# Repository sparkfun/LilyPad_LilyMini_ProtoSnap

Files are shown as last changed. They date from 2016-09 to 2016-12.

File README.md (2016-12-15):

LilyMini ProtoSnap
========================================

(https://cdn.sparkfun.com/assets/parts/1/1/9/0/5/14063-01.jpg)

[*LilyMini ProtoSnap (https://www.sparkfun.com/products/14063)*](https://www.sparkfun.com/products/14063)

The LilyMini ProtoSnap is a great way to create interactive e-textile circuits. At the center of the board is a pre-programmed LilyMini microcontroller connected to a LilyPad Light Sensor, LilyPad Button and two pairs of LilyPad LEDs.

Like other ProtoSnap boards, the LilyMini ProtoSnap has all of these parts connected together on the board, enabling you to play with the circuit before you sew. When you're ready to make your project, snap out the parts and sew them together!

The LilyMini ProtoSnap ships with pre-loaded code that exercises all the LilyPad pieces connected to it. The sample code has three modes, which can be selected by pressing the LilyPad Button on the bottom-left side of the ProtoSnap. The built-in RGB LED on the LilyMini will change color to indicate which mode has been selected:

* White: All LEDs on.
* Magenta: LEDs fade in and out in a breathing pattern. When the light sensor is covered, LEDs fade faster.
* Cyan/Blue: When the board is in darkness, the LEDs will twinkle (perfect for night-lights)

You can use the built-in code to make your own projects (see the hook-up guide below), or you can reprogram the LilyMini using the Arduino system . **Reprogramming instructions coming soon (1/1/17).** 

Repository Contents
-------------------

This repository includes the hardware design files and binaries for the release firmware. <br>
**Reprogramming information and source code are coming soon (1/1/17).** 

* **/Documentation** - Data sheets, additional product information
* **/Firmware** - Preinstalled code 
* **/Hardware** - Eagle design files (.brd, .sch)
* **/Production** - Production panel files (.brd)

Documentation
--------------
* **[Hookup Guide](https://learn.sparkfun.com/tutorials/lilymini-protosnap-hookup-guide)** - Basic hookup guide and example projects for the LilyMini ProtoSnap

License Information
-------------------

This product is _**open source**_! Please review the LICENSE.md file for license information. If you have any questions or concerns on licensing, please contact techsupport@sparkfun.com. This information is distributed as-is; no warranty is given.

Have fun! - Your friends at SparkFun.

Acknowledgement
---------------

We gratefully acknowledge the following people and groups for their open-source contributions:

* Arduino LLC and Atmel Corporation/Thibaut Viard for bringing Arduino support to the SAMD21.
* Justin Mattair of [Mattairtech, Inc.](https://www.mattairtech.com/) for porting Arduino's SAMD21 bootloader and Shumatech's BOSSAC to the SAMD11.

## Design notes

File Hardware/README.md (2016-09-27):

SparkFun <PRODUCT NAME> Design Files
=====================================

The .sch and .brd files hare are Eagle CAD schematic and PCB design files from SparkFun Electronics.
A freeware version of Eagle can be found [here](http://www.cadsoftusa.com/download-eagle/freeware/).

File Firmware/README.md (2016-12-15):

LilyMini ProtoSnap Firmware
===================================

These binary files require a hardware programmer such as the Atmel-ICE for installation. See schematic for pinout information. **Arduino support coming soon (1/1/17)**

bootloader_samd11_sam_ba.hex - SAMD11 bootloader binary

LilyMini signed Windows driver.zip - Windows Driver

LilyMini_Protosnap_Light_Sensor_Arduino_V10.ino.bin - Example code binary

LilyMini_Protosnap_Light_Sensor_combined_V10.hex - Combined bootloader and example binary

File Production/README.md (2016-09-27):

SparkFun <PRODUCT NAME> Production Files
=========================================

These are the production files SparkFun uses for printing PCBs.

License Information
-------------------
This product is open source! 

The hardware is released under [Creative Commons ShareAlike 4.0 International](https://creativecommons.org/licenses/by-sa/4.0/).

Please use, reuse, and modify these files as you see fit. Please maintain attribution to SparkFun Electronics and release anything derivative under the same license.

Distributed as-is; no warranty is given.

- Your friends at SparkFun.

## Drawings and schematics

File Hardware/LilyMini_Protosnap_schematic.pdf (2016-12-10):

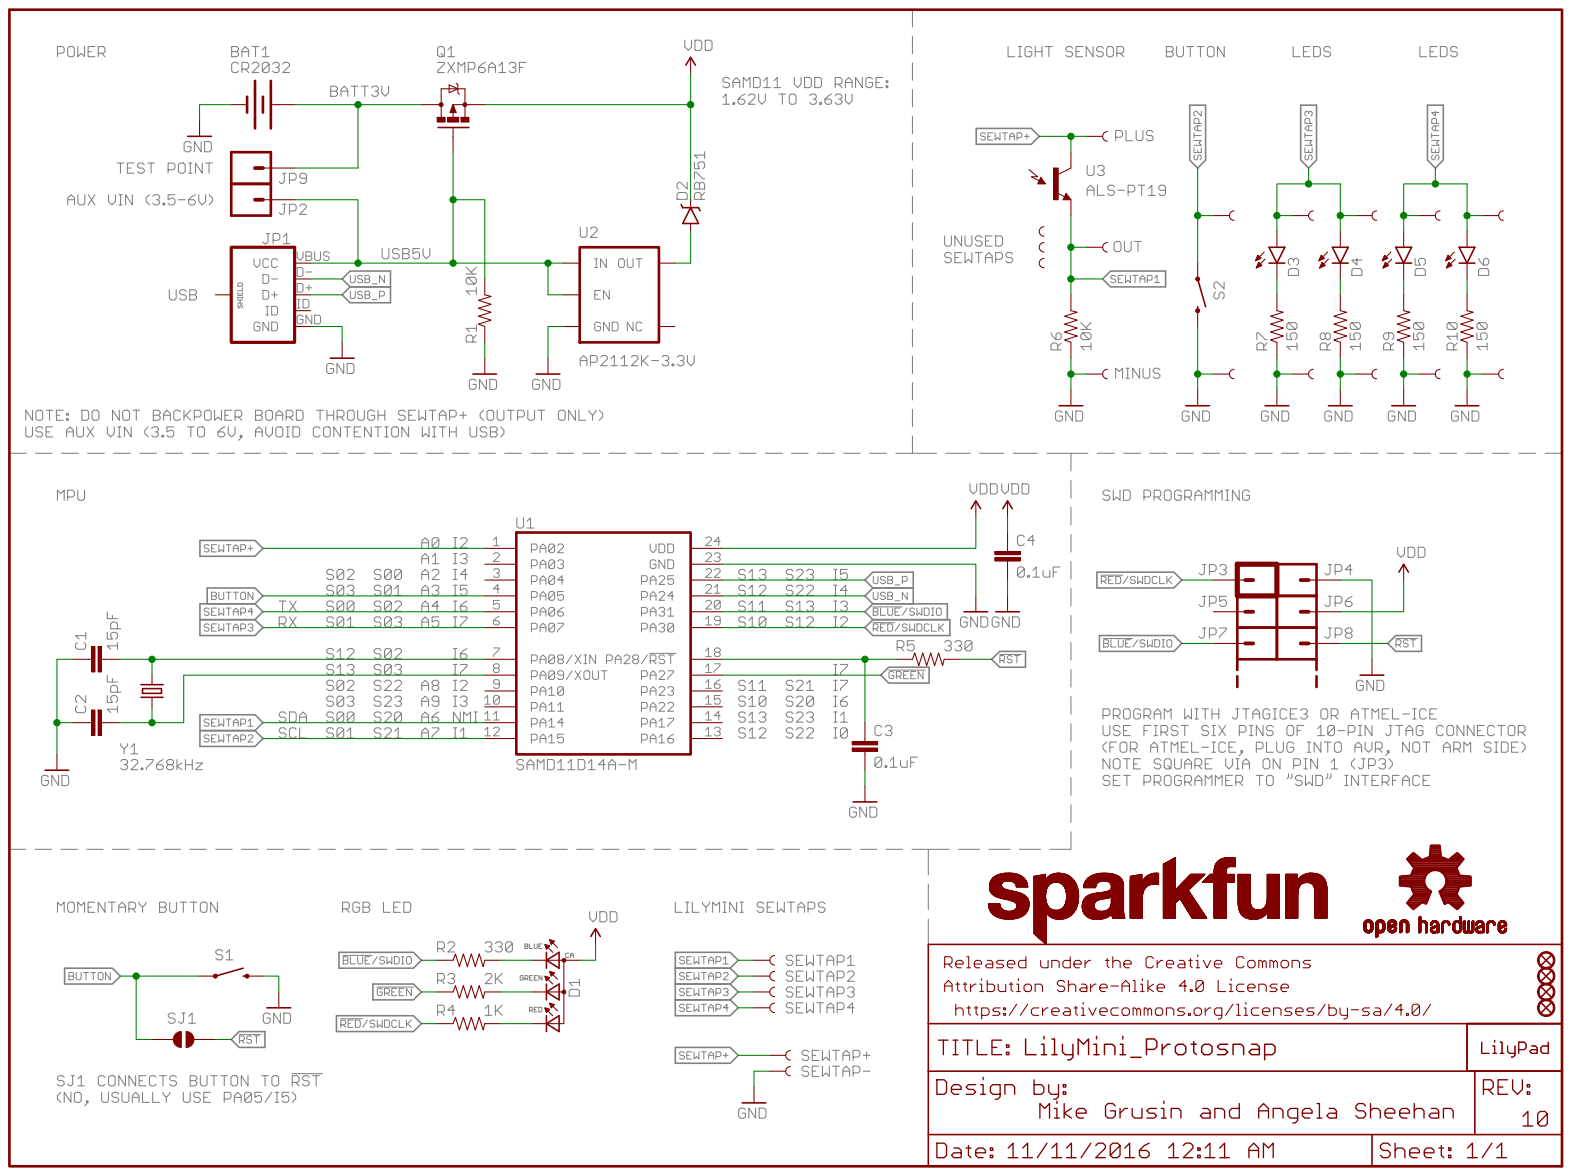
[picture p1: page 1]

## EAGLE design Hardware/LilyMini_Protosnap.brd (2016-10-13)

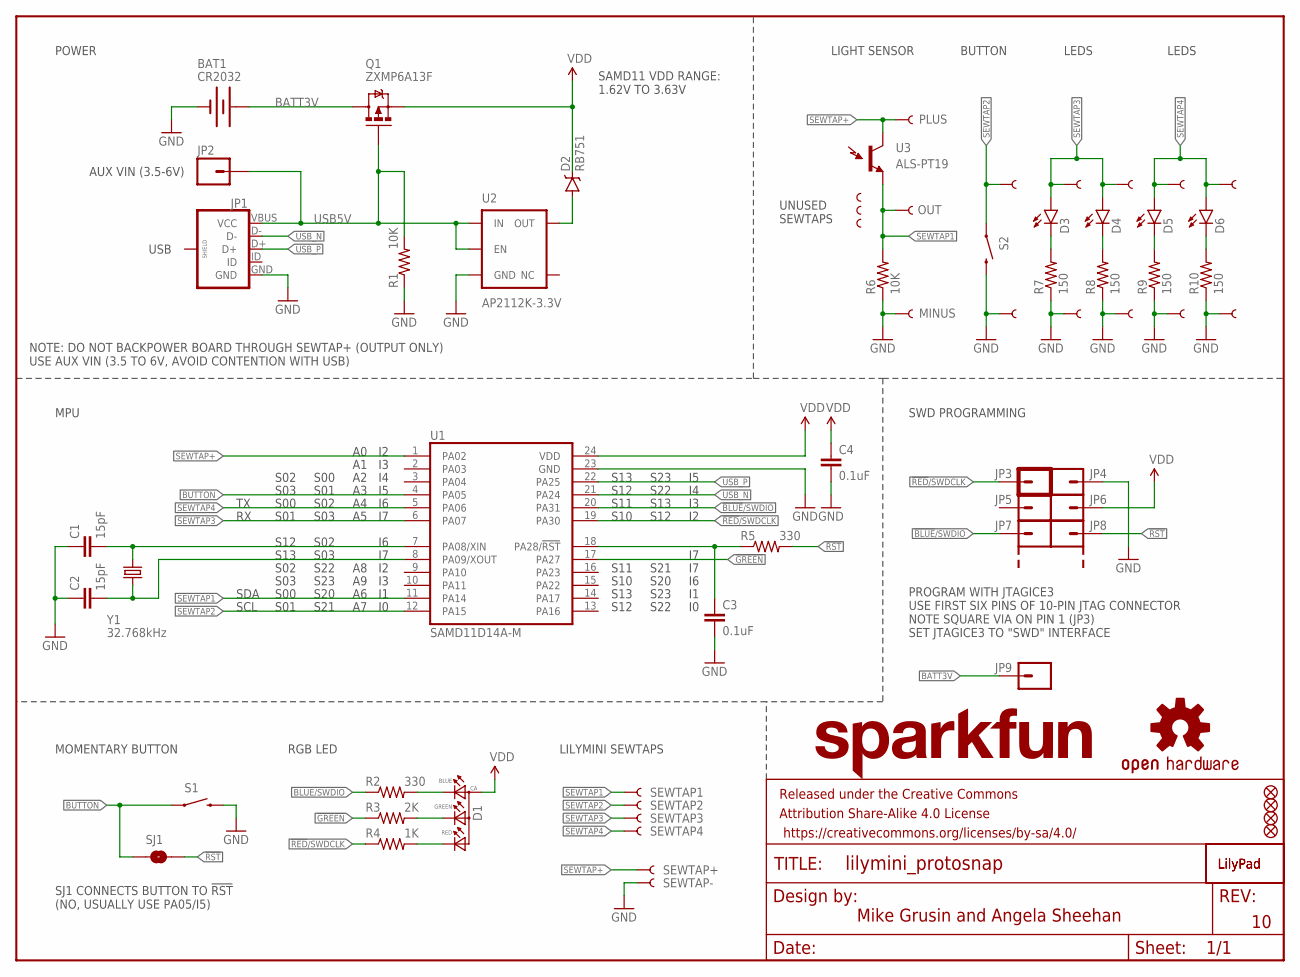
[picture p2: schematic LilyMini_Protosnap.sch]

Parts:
$1_61_$_2016-09-25_21-56-09: OSHW-LOGOS; OSHW-LOGO-S
BAT1: CR2032; BATTERY_20MM_PTH_KIT
C1, C2: 15pF; 0603-CAP
C3, C4: 0.1uF; 0603-CAP
D1: 0.13_RGB_LEDPLCC; P-LCC-4-3
D2: RB751; SOD-523
D3, D4, D5, D6: LED-WHITE1206; LED-1206
FD1, FD2, FD3, FD4: FIDUCIAL1X2; FIDUCIAL-1X2
FRAME1: FRAME-LETTER; CREATIVE_COMMONS
JP1: USB_MICROB_PLUGUSB-B-MICRO-SMD-VERT; USB-B-MICRO-SMD_VERT
JP2: M01SMDNS; 1X01NS
JP3: M01_POGOPAD_20M_NS_1S_SQUARE; 1X01_POGOPIN_PAD_NOSILK_1SIDE_SQUARE
JP4, JP5, JP6, JP7, JP8, JP9: M01_POGOPAD_20M_NS_1S_ROUND; 1X01_POGOPIN_PAD_NOSILK_1SIDE_ROUND
JP12, JP13: SEWTAP8; PETAL-MEDIUM-2SIDE
JP20, JP21, JP22, JP23, JP24, JP25, JP26, JP27: SEWTAP6; PETAL-SMALL-2SIDE
LOGO1: LOGO-LPL; LOGO-L
LOGO2: LILYLOGO-L-TOP; LOGO-L-TOP
LOGO4: SFE_LOGO_NAME.1_INCH; SFE_LOGO_NAME_.1
Q1: ZXMP6A13F; SOT23-3
R1, R6: 10K; 0603-RES
R2, R5: 330; 0603-RES
R3: 2K; 0603-RES
R4: 1K; 0603-RES
R7, R8, R9, R10: 150; 0603-RES
S1: SWITCH-MOMENTARY-2SMD-4.6X2.8MM; TACTILE_SWITCH_SMD_4.6X2.8MM
S2: SWITCH-MOMENTARY-2SMD-REDUNDANT; TACTILE-SWITCH-SMD
SEWTAP1, SEWTAP2, SEWTAP3, SEWTAP4: SEWTAP8; PETAL-MEDIUM-2SIDE
SEWTAP+: SEWTAP8; PETAL-MEDIUM-2SIDE
SEWTAP-: SEWTAP8; PETAL-MEDIUM-2SIDE
SEWTAPLS+: PLUS; PETAL-SMALL-2SIDE
SEWTAPLS-: MINUS; PETAL-SMALL-2SIDE
SEWTAPLSOUT: OUT; PETAL-SMALL-2SIDE
SJ1: JUMPER-PAD-2-NO; PAD-JUMPER-2-NO_NO_SILK
ST1, ST2, ST3: SEWTAP-NOHOLE2; PETAL-NOHOLE-2SIDE
U1: SAMD11D14A-M; QFN-24_ALT2
U2: AP2112K-3.3V; SOT23-5
U3: ALS-PT19
Y1: 32.768kHz; CRYSTAL-SMD-3.2X1.5MM

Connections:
!BLUE!/SWDIO: JP7.P$1, R2.1, U1.20 (PA31)
!GREEN!: R3.1, U1.17 (PA27)
!RED!/SWDCLK: JP3.P$1, R4.1, U1.19 (PA30)
!RST!: JP8.P$1, R5.2, SJ1.2
!RST!1: C3.1, R5.1, U1.18 (PA28/!RST!)
B: D1.3 (BLUE), R2.2
BATT3V: BAT1.+1 (+), BAT1.+2 (+), JP9.P$1, Q1.3 (D)
BUTTON: S1.1, S1.2 (1), SJ1.1, U1.4 (PA05)
G: D1.2 (GREEN), R3.2
GND: BAT1.-3 (-), C1.1, C2.1, C3.2, C4.2, JP1.GND, JP4.P$1, JP13.1, JP21.1, JP23.1, JP25.1, JP27.1, R1.1, R6.1, R7.1, R8.1, R9.1, R10.1, S1.3 (2), S1.4 (2), S2.3 (2), S2.4 (2), SEWTAP-.1, SEWTAPLS-.1, U1.23 (GND), U2.2 (GND)
unnamed: D2.A, U2.5 (OUT)
unnamed: D3.C, R7.2
unnamed: D4.C, R8.2
unnamed: D5.C, R9.2
unnamed: D6.C, R10.2
R: D1.1 (RED), R4.2
SEWTAP1: R6.2, SEWTAP1.1, SEWTAPLSOUT.1, U1.11 (PA14), U3.E (E1)
SEWTAP2: JP12.1, S2.1, S2.2 (1), SEWTAP2.1, U1.12 (PA15)
SEWTAP3: D3.A, D4.A, JP20.1, JP22.1, SEWTAP3.1, U1.6 (PA07)
SEWTAP4: D5.A, D6.A, JP24.1, JP26.1, SEWTAP4.1, U1.5 (PA06)
SEWTAP+: SEWTAP+.1, SEWTAPLS+.1, U1.1 (PA02), U3.C (C1)
USB5V: JP1.VBUS (VCC), JP2.1, Q1.1 (G), R1.2, U2.1 (IN), U2.3 (EN)
USB_N: JP1.D-, U1.21 (PA24)
USB_P: JP1.D+, U1.22 (PA25)
VDD: C4.1, D1.4 (ANODE), D2.C, JP6.P$1, Q1.2 (S), U1.24 (VDD)
X1: C1.2, U1.7 (PA08/XIN), Y1.P$2 (2)
X2: C2.2, U1.8 (PA09/XOUT), Y1.P$1 (1)

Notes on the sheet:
PROGRAM WITH JTAGICE3 USE FIRST SIX PINS OF 10-PIN JTAG CONNECTOR NOTE SQUARE VIA ON PIN 1 (JP3) SET JTAGICE3 TO "SWD" INTERFACE
SAMD11 VDD RANGE: 1.62V TO 3.63V
SWD PROGRAMMING
RGB LED
MOMENTARY BUTTON
S00
S01
S03
S02
SDA
SCL
AUX VIN (3.5-6V)
UNUSED SEWTAPS
Mike Grusin and Angela Sheehan
LILYMINI SEWTAPS
S22
S23
S20
S21
LIGHT SENSOR
BUTTON
LEDS
USB
NOTE: DO NOT BACKPOWER BOARD THROUGH SEWTAP+ (OUTPUT ONLY) USE AUX VIN (3.5 TO 6V, AVOID CONTENTION WITH USB)
S12
S13
S11
S10
POWER
MPU
SJ1 CONNECTS BUTTON TO !RST! (NO, USUALLY USE PA05/I5)

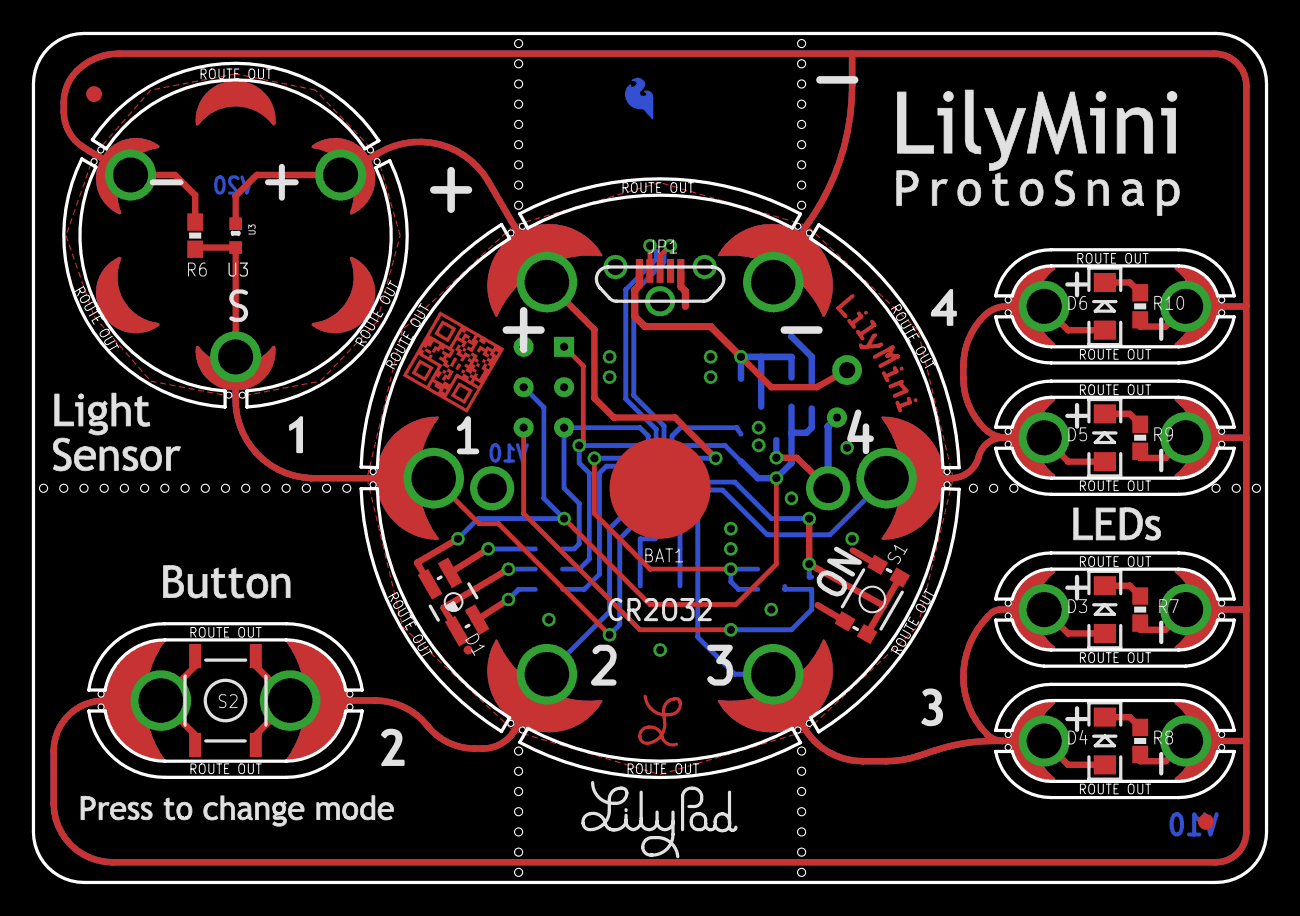
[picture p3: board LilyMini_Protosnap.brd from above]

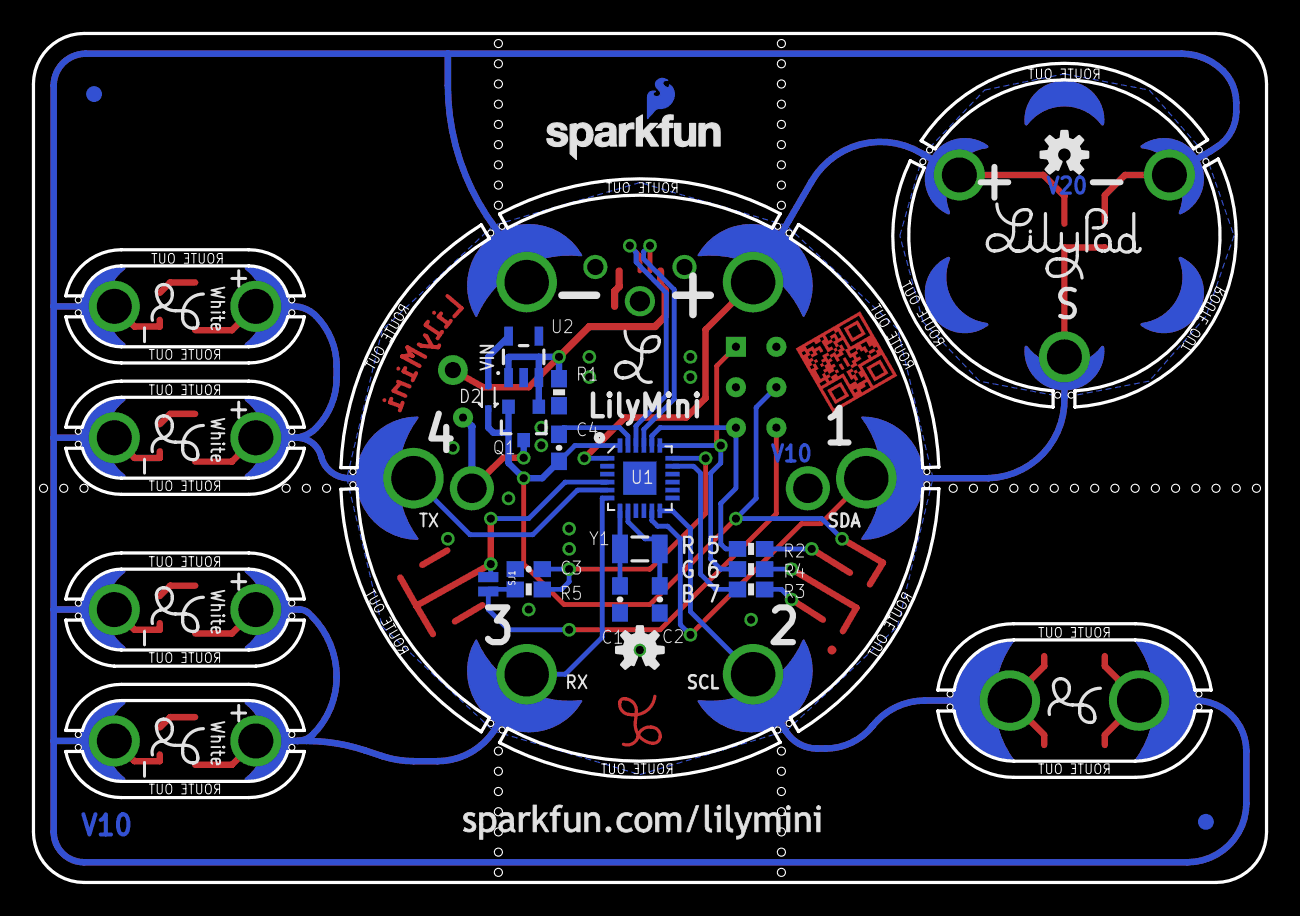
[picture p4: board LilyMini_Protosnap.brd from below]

Board: 2 copper layers, 77.5 x 53.3 mm, 78 parts (35 on the bottom side), 27 nets.

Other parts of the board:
LOGO3: OSHW-LOGOS; OSHW-LOGO-S
U$1: LOGO-LILYPAD
U$2: LOGO-LPLP; LOGO-LILYPAD
U$4: SFE_LOGO_FLAME_COPPER_EXPOSED_.1
U$5, U$6, U$7, U$8, U$9: LOGO-L

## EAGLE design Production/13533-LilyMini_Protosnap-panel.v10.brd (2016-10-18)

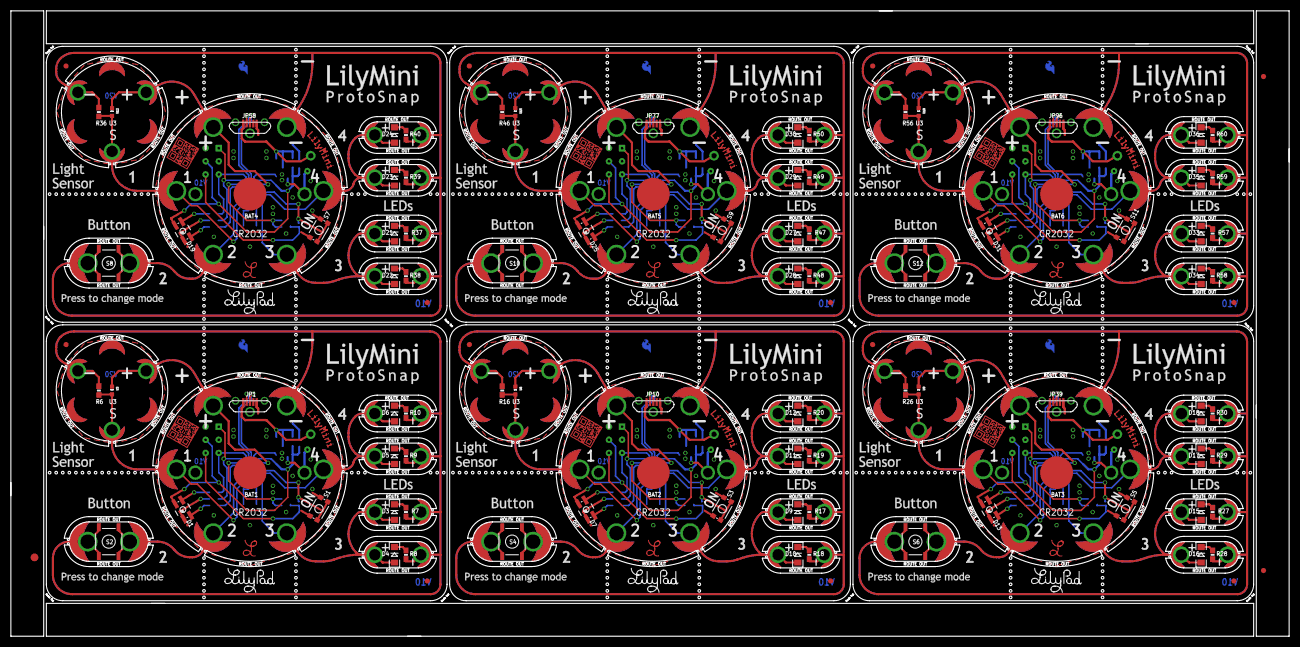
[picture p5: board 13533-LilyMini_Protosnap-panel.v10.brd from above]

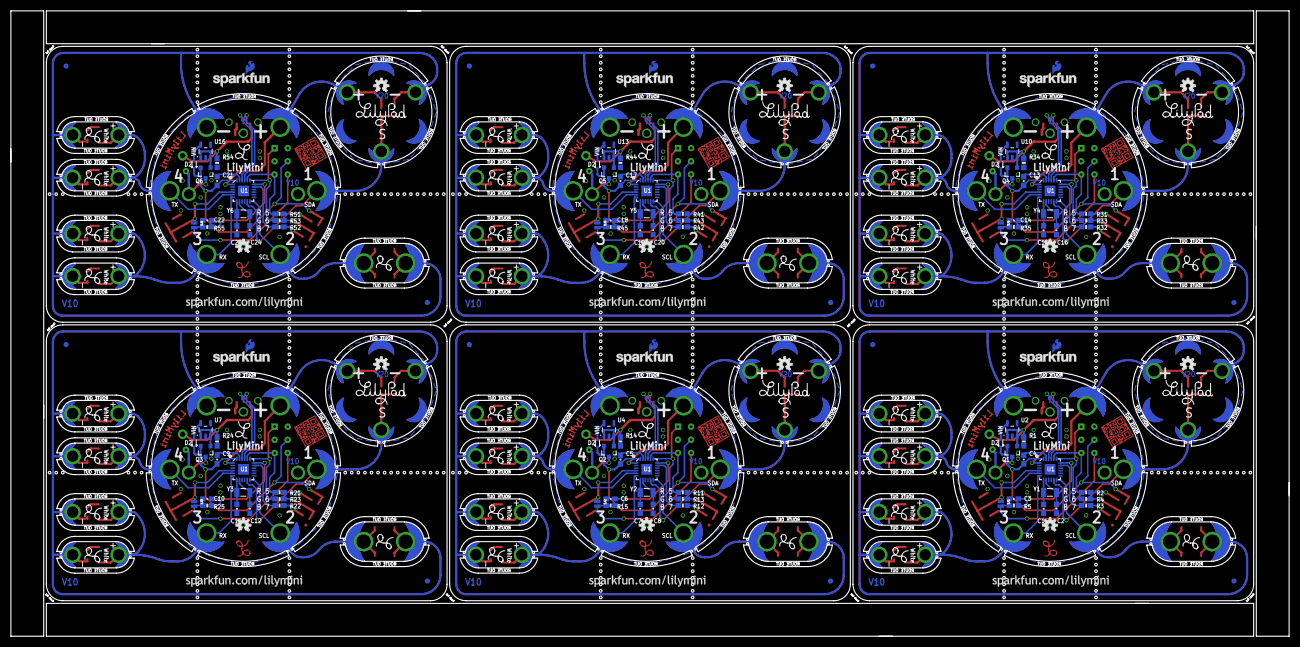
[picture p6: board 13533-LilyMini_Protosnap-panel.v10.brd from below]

Board: 2 copper layers, 247.1 x 120.9 mm, 465 parts (210 on the bottom side), 162 nets.

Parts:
$1_61_$_2016-09-25_21-56-01, $1_61_$_2016-09-25_21-56-02, $1_61_$_2016-09-25_21-56-03, $1_61_$_2016-09-25_21-56-04, $1_61_$_2016-09-25_21-56-05, $1_61_$_2016-09-25_21-56-09: OSHW-LOGOS; OSHW-LOGO-S
BAT1, BAT2, BAT3, BAT4, BAT5, BAT6: CR2032; BATTERY_20MM_PTH_KIT
C1, C2, C7, C8, C11, C12, C15, C16, C19, C20, C23, C24: 15pF; 0603-CAP
C3, C4, C5, C6, C9, C10, C13, C14, C17, C18, C21, C22: 0.1uF; 0603-CAP
D1, D7, D13, D19, D25, D31: P-LCC-4-3
D2, D8, D14, D20, D26, D32: RB751; SOD-523
D3, D4, D5, D6, D9, D10, D11, D12, D15, D16, D17, D18, D21, D22, D23, D24, D27, D28, D29, D30, D33, D34, D35, D36: LED-1206
E$1: FIDUCIAL-1.5X3
E$7, E$8: FIDUCIAL-1X2
FD1, FD2, FD3, FD4, FD5, FD6, FD7, FD8, FD9, FD10, FD11, FD12, FD13, FD14, FD15, FD16, FD17, FD18, FD19, FD20, FD21, FD22, FD23, FD24: FIDUCIAL1X2; FIDUCIAL-1X2
JP1, JP10, JP39, JP58, JP77, JP96: USB-B-MICRO-SMD_VERT
JP2, JP19, JP46, JP65, JP84, JP103: 1X01NS
JP3, JP11, JP40, JP59, JP78, JP97: 1X01_POGOPIN_PAD_NOSILK_1SIDE_SQUARE
JP4, JP5, JP6, JP7, JP8, JP9, JP14, JP15, JP16, JP17, JP18, JP38, JP41, JP42, JP43, JP44, JP45, JP57, JP60, JP61, JP62, JP63, JP64, JP76, JP79, JP80, JP81, JP82, JP83, JP95, JP98, JP99, JP100, JP101, JP102, JP114: 1X01_POGOPIN_PAD_NOSILK_1SIDE_ROUND
JP12, JP13, JP32, JP33, JP51, JP52, JP70, JP71, JP89, JP90, JP108, JP109: PETAL-MEDIUM-2SIDE
JP20, JP21, JP22, JP23, JP24, JP25, JP26, JP27, JP28, JP29, JP30, JP31, JP34, JP35, JP36, JP37, JP47, JP48, JP49, JP50, JP53, JP54, JP55, JP56, JP66, JP67, JP68, JP69, JP72, JP73, JP74, JP75, JP85, JP86, JP87, JP88, JP91, JP92, JP93, JP94, JP104, JP105, JP106, JP107, JP110, JP111, JP112, JP113: PETAL-SMALL-2SIDE
LOGO1, LOGO5, LOGO9, LOGO13, LOGO17, LOGO21: LOGO-L
LOGO2, LOGO6, LOGO10, LOGO14, LOGO18, LOGO22: LOGO-L-TOP
LOGO3, LOGO7, LOGO11, LOGO15, LOGO19, LOGO23: OSHW-LOGOS; OSHW-LOGO-S
LOGO4, LOGO8, LOGO12, LOGO16, LOGO20, LOGO24: SFE_LOGO_NAME.1_INCH; SFE_LOGO_NAME_.1
Q1, Q2, Q3, Q4, Q5, Q6: ZXMP6A13F; SOT23-3
R1, R6, R14, R16, R24, R26, R34, R36, R44, R46, R54, R56: 10K; 0603-RES
R2, R5, R11, R15, R21, R25, R31, R35, R41, R45, R51, R55: 330; 0603-RES
R3, R12, R22, R32, R42, R52: 2K; 0603-RES
R4, R13, R23, R33, R43, R53: 1K; 0603-RES
R7, R8, R9, R10, R17, R18, R19, R20, R27, R28, R29, R30, R37, R38, R39, R40, R47, R48, R49, R50, R57, R58, R59, R60: 150; 0603-RES
S1, S3, S5, S7, S9, S11: TACTILE_SWITCH_SMD_4.6X2.8MM
S2, S4, S6, S8, S10, S12: TACTILE-SWITCH-SMD
SEWTAP1, SEWTAP2, SEWTAP3, SEWTAP4, SEWTAP5, SEWTAP6, SEWTAP7, SEWTAP8, SEWTAP9, SEWTAP10, SEWTAP11, SEWTAP12, SEWTAP13, SEWTAP14, SEWTAP15, SEWTAP16, SEWTAP17, SEWTAP18, SEWTAP19, SEWTAP20, SEWTAP21, SEWTAP22, SEWTAP23, SEWTAP24: PETAL-MEDIUM-2SIDE
SEWTAP+, SEWTAP+1, SEWTAP+2, SEWTAP+3, SEWTAP+4, SEWTAP+5: PETAL-MEDIUM-2SIDE
SEWTAP-, SEWTAP-1, SEWTAP-2, SEWTAP-3, SEWTAP-4, SEWTAP-5: PETAL-MEDIUM-2SIDE
SEWTAPLS+, SEWTAPLS+1, SEWTAPLS+2, SEWTAPLS+3, SEWTAPLS+4, SEWTAPLS+5: PLUS; PETAL-SMALL-2SIDE
SEWTAPLS-, SEWTAPLS-1, SEWTAPLS-2, SEWTAPLS-3, SEWTAPLS-4, SEWTAPLS-5: MINUS; PETAL-SMALL-2SIDE
SEWTAPLSOUT, SEWTAPLSOUT1, SEWTAPLSOUT2, SEWTAPLSOUT3, SEWTAPLSOUT4, SEWTAPLSOUT5: OUT; PETAL-SMALL-2SIDE
SJ1, SJ2, SJ3, SJ4, SJ5, SJ6: PAD-JUMPER-2-NO_NO_SILK
ST1, ST2, ST3, ST4, ST5, ST6, ST7, ST8, ST9, ST10, ST11, ST12, ST13, ST14, ST15, ST16, ST17, ST18: PETAL-NOHOLE-2SIDE
U1, U5, U8, U11, U14, U17: SAMD11D14A-M; QFN-24_ALT2
U2, U4, U7, U10, U13, U16: AP2112K-3.3V; SOT23-5
U3, U6, U9, U12, U15, U18: ALS-PT19
U$1, U$13, U$21, U$29, U$37, U$45: LOGO-LILYPAD
U$2, U$3, U$17, U$25, U$33, U$41: LOGO-LPLP; LOGO-LILYPAD
U$4, U$10, U$18, U$26, U$34, U$42: SFE_LOGO_FLAME_COPPER_EXPOSED_.1
U$5, U$6, U$7, U$8, U$9, U$11, U$12, U$14, U$15, U$16, U$19, U$20, U$22, U$23, U$24, U$27, U$28, U$30, U$31, U$32, U$35, U$36, U$38, U$39, U$40, U$43, U$44, U$46, U$47, U$48: LOGO-L
Y1, Y2, Y3, Y4, Y5, Y6: 32.768kHz; CRYSTAL-SMD-3.2X1.5MM

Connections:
!BLUE!/SWDIO: JP7.P$1, R2.1, U1.20
!BLUE!/SWDIO1: JP17.P$1, R11.1, U5.20
!BLUE!/SWDIO2: JP44.P$1, R21.1, U8.20
!BLUE!/SWDIO3: JP63.P$1, R31.1, U11.20
!BLUE!/SWDIO4: JP82.P$1, R41.1, U14.20
!BLUE!/SWDIO5: JP101.P$1, R51.1, U17.20
!GREEN!: R3.1, U1.17
!GREEN!1: R12.1, U5.17
!GREEN!2: R22.1, U8.17
!GREEN!3: R32.1, U11.17
!GREEN!4: R42.1, U14.17
!GREEN!5: R52.1, U17.17
!RED!/SWDCLK: JP3.P$1, R4.1, U1.19
!RED!/SWDCLK1: JP11.P$1, R13.1, U5.19
!RED!/SWDCLK2: JP40.P$1, R23.1, U8.19
!RED!/SWDCLK3: JP59.P$1, R33.1, U11.19
!RED!/SWDCLK4: JP78.P$1, R43.1, U14.19
!RED!/SWDCLK5: JP97.P$1, R53.1, U17.19
!RST!: JP8.P$1, R5.2, SJ1.2
!RST!1: C3.1, R5.1, U1.18
!RST!2: JP18.P$1, R15.2, SJ2.2
!RST!3: C6.1, R15.1, U5.18
!RST!4: JP45.P$1, R25.2, SJ3.2
!RST!5: C10.1, R25.1, U8.18
!RST!6: JP64.P$1, R35.2, SJ4.2
!RST!7: C14.1, R35.1, U11.18
!RST!8: JP83.P$1, R45.2, SJ5.2
!RST!9: C18.1, R45.1, U14.18
!RST!10: JP102.P$1, R55.2, SJ6.2
!RST!11: C22.1, R55.1, U17.18
B: D1.3, R2.2
B1: D7.3, R11.2
B2: D13.3, R21.2
B3: D19.3, R31.2
B4: D25.3, R41.2
B5: D31.3, R51.2
BATT3V: BAT1.+1, BAT1.+2, JP9.P$1, Q1.3
BATT3V1: BAT2.+1, BAT2.+2, JP38.P$1, Q2.3
BATT3V2: BAT3.+1, BAT3.+2, JP57.P$1, Q3.3
BATT3V3: BAT4.+1, BAT4.+2, JP76.P$1, Q4.3
BATT3V4: BAT5.+1, BAT5.+2, JP95.P$1, Q5.3
BATT3V5: BAT6.+1, BAT6.+2, JP114.P$1, Q6.3
BUTTON: S1.1, S1.2, SJ1.1, U1.4
BUTTON1: S3.1, S3.2, SJ2.1, U5.4
BUTTON2: S5.1, S5.2, SJ3.1, U8.4
BUTTON3: S7.1, S7.2, SJ4.1, U11.4
BUTTON4: S9.1, S9.2, SJ5.1, U14.4
BUTTON5: S11.1, S11.2, SJ6.1, U17.4
G: D1.2, R3.2
G1: D7.2, R12.2
G2: D13.2, R22.2
G3: D19.2, R32.2
G4: D25.2, R42.2
G5: D31.2, R52.2
GND: BAT1.-3, C1.1, C2.1, C3.2, C4.2, JP1.GND, JP4.P$1, JP13.1, JP21.1, JP23.1, JP25.1, JP27.1, R1.1, R6.1, R7.1, R8.1, R9.1, R10.1, S1.3, S1.4, S2.3, S2.4, SEWTAP-.1, SEWTAPLS-.1, U1.23, U2.2
GND1: BAT2.-3, C5.2, C6.2, C7.1, C8.1, JP10.GND, JP14.P$1, JP28.1, JP29.1, JP30.1, JP31.1, JP32.1, R14.1, R16.1, R17.1, R18.1, R19.1, R20.1, S3.3, S3.4, S4.3, S4.4, SEWTAP-1.1, SEWTAPLS-1.1, U4.2, U5.23
GND3: BAT3.-3, C9.2, C10.2, C11.1, C12.1, JP39.GND, JP41.P$1, JP47.1, JP48.1, JP49.1, JP50.1, JP51.1, R24.1, R26.1, R27.1, R28.1, R29.1, R30.1, S5.3, S5.4, S6.3, S6.4, SEWTAP-2.1, SEWTAPLS-2.1, U7.2, U8.23
GND6: BAT4.-3, C13.2, C14.2, C15.1, C16.1, JP58.GND, JP60.P$1, JP66.1, JP67.1, JP68.1, JP69.1, JP70.1, R34.1, R36.1, R37.1, R38.1, R39.1, R40.1, S7.3, S7.4, S8.3, S8.4, SEWTAP-3.1, SEWTAPLS-3.1, U10.2, U11.23
GND8: BAT5.-3, C17.2, C18.2, C19.1, C20.1, JP77.GND, JP79.P$1, JP85.1, JP86.1, JP87.1, JP88.1, JP89.1, R44.1, R46.1, R47.1, R48.1, R49.1, R50.1, S9.3, S9.4, S10.3, S10.4, SEWTAP-4.1, SEWTAPLS-4.1, U13.2, U14.23
GND10: BAT6.-3, C21.2, C22.2, C23.1, C24.1, JP96.GND, JP98.P$1, JP104.1, JP105.1, JP106.1, JP107.1, JP108.1, R54.1, R56.1, R57.1, R58.1, R59.1, R60.1, S11.3, S11.4, S12.3, S12.4, SEWTAP-5.1, SEWTAPLS-5.1, U16.2, U17.23
unnamed: D2.A, U2.5
unnamed: D3.C, R7.2
unnamed: D4.C, R8.2
unnamed: D5.C, R9.2
unnamed: D6.C, R10.2
unnamed: D8.A, U4.5
unnamed: D9.C, R17.2
unnamed: D10.C, R18.2
unnamed: D11.C, R19.2
unnamed: D12.C, R20.2
unnamed: D14.A, U7.5
unnamed: D15.C, R27.2
unnamed: D16.C, R28.2
unnamed: D17.C, R29.2
unnamed: D18.C, R30.2
unnamed: D20.A, U10.5
unnamed: D21.C, R37.2
unnamed: D22.C, R38.2
unnamed: D23.C, R39.2
unnamed: D24.C, R40.2
unnamed: D26.A, U13.5
unnamed: D27.C, R47.2
unnamed: D28.C, R48.2
unnamed: D29.C, R49.2
unnamed: D30.C, R50.2
unnamed: D32.A, U16.5
unnamed: D33.C, R57.2
unnamed: D34.C, R58.2
unnamed: D35.C, R59.2
unnamed: D36.C, R60.2
R: D1.1, R4.2
R1: D7.1, R13.2
R2: D13.1, R23.2
R3: D19.1, R33.2
R4: D25.1, R43.2
R5: D31.1, R53.2
SEWTAP1: R6.2, SEWTAP1.1, SEWTAPLSOUT.1, U1.11, U3.E
SEWTAP2: JP12.1, S2.1, S2.2, SEWTAP2.1, U1.12
SEWTAP3: D3.A, D4.A, JP20.1, JP22.1, SEWTAP3.1, U1.6
SEWTAP4: D5.A, D6.A, JP24.1, JP26.1, SEWTAP4.1, U1.5
SEWTAP9: R16.2, SEWTAP5.1, SEWTAPLSOUT1.1, U5.11, U6.E
SEWTAP10: JP33.1, S4.1, S4.2, SEWTAP6.1, U5.12
SEWTAP11: D11.A, D12.A, JP36.1, JP37.1, SEWTAP8.1, U5.5
SEWTAP12: D9.A, D10.A, JP34.1, JP35.1, SEWTAP7.1, U5.6
SEWTAP17: R26.2, SEWTAP9.1, SEWTAPLSOUT2.1, U8.11, U9.E
SEWTAP18: JP52.1, S6.1, S6.2, SEWTAP10.1, U8.12
SEWTAP19: D17.A, D18.A, JP55.1, JP56.1, SEWTAP12.1, U8.5
SEWTAP20: D15.A, D16.A, JP53.1, JP54.1, SEWTAP11.1, U8.6
SEWTAP25: R36.2, SEWTAP13.1, SEWTAPLSOUT3.1, U11.11, U12.E
SEWTAP26: JP71.1, S8.1, S8.2, SEWTAP14.1, U11.12
SEWTAP27: D23.A, D24.A, JP74.1, JP75.1, SEWTAP16.1, U11.5
SEWTAP28: D21.A, D22.A, JP72.1, JP73.1, SEWTAP15.1, U11.6
SEWTAP33: R46.2, SEWTAP17.1, SEWTAPLSOUT4.1, U14.11, U15.E
SEWTAP34: JP90.1, S10.1, S10.2, SEWTAP18.1, U14.12
SEWTAP35: D29.A, D30.A, JP93.1, JP94.1, SEWTAP20.1, U14.5
SEWTAP36: D27.A, D28.A, JP91.1, JP92.1, SEWTAP19.1, U14.6
SEWTAP41: R56.2, SEWTAP21.1, SEWTAPLSOUT5.1, U17.11, U18.E
SEWTAP42: JP109.1, S12.1, S12.2, SEWTAP22.1, U17.12
SEWTAP43: D35.A, D36.A, JP112.1, JP113.1, SEWTAP24.1, U17.5
SEWTAP44: D33.A, D34.A, JP110.1, JP111.1, SEWTAP23.1, U17.6
SEWTAP+: SEWTAP+.1, SEWTAPLS+.1, U1.1, U3.C
SEWTAP+2: SEWTAP+1.1, SEWTAPLS+1.1, U5.1, U6.C
SEWTAP+4: SEWTAP+2.1, SEWTAPLS+2.1, U8.1, U9.C
SEWTAP+6: SEWTAP+3.1, SEWTAPLS+3.1, U11.1, U12.C
SEWTAP+8: SEWTAP+4.1, SEWTAPLS+4.1, U14.1, U15.C
SEWTAP+10: SEWTAP+5.1, SEWTAPLS+5.1, U17.1, U18.C
USB5V: JP1.VBUS, JP2.1, Q1.1, R1.2, U2.1, U2.3
USB5V1: JP10.VBUS, JP19.1, Q2.1, R14.2, U4.1, U4.3
USB5V2: JP39.VBUS, JP46.1, Q3.1, R24.2, U7.1, U7.3
USB5V3: JP58.VBUS, JP65.1, Q4.1, R34.2, U10.1, U10.3
USB5V4: JP77.VBUS, JP84.1, Q5.1, R44.2, U13.1, U13.3
USB5V5: JP96.VBUS, JP103.1, Q6.1, R54.2, U16.1, U16.3
USB_N: JP1.D-, U1.21
USB_N1: JP10.D-, U5.21
USB_N2: JP39.D-, U8.21
USB_N3: JP58.D-, U11.21
USB_N4: JP77.D-, U14.21
USB_N5: JP96.D-, U17.21
USB_P: JP1.D+, U1.22
USB_P1: JP10.D+, U5.22
USB_P2: JP39.D+, U8.22
USB_P3: JP58.D+, U11.22
USB_P4: JP77.D+, U14.22
USB_P5: JP96.D+, U17.22
VDD: C4.1, D1.4, D2.C, JP6.P$1, Q1.2, U1.24
VDD1: C5.1, D7.4, D8.C, JP16.P$1, Q2.2, U5.24
VDD2: C9.1, D13.4, D14.C, JP43.P$1, Q3.2, U8.24
VDD3: C13.1, D19.4, D20.C, JP62.P$1, Q4.2, U11.24
VDD4: C17.1, D25.4, D26.C, JP81.P$1, Q5.2, U14.24
VDD5: C21.1, D31.4, D32.C, JP100.P$1, Q6.2, U17.24
X1: C1.2, U1.7, Y1.P$2
X2: C2.2, U1.8, Y1.P$1
X3: C8.2, U5.8, Y2.P$1
X4: C7.2, U5.7, Y2.P$2
X5: C12.2, U8.8, Y3.P$1
X6: C11.2, U8.7, Y3.P$2
X7: C16.2, U11.8, Y4.P$1
X8: C15.2, U11.7, Y4.P$2
X9: C20.2, U14.8, Y5.P$1
X10: C19.2, U14.7, Y5.P$2
X11: C24.2, U17.8, Y6.P$1
X12: C23.2, U17.7, Y6.P$2

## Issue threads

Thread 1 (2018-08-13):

Vertical USB?

R-OLE, 2018-08-13:
If there is the intent to sew this board to cloth or other materials, why would you put the USB connector sticking out of the PCB plane?
Seems that would be:
- uncomfortable if pressed against skin
- greatly increase the chances of snagging on supporting material or other "things"
- greatly increase the chances of damaging the PCB or even snapping-off the USB connector

R-OLE, 2018-08-13:
It would also make it more difficult to provide power via USB cable in an application, as the cable would not be laying down.

R-OLE, 2018-08-13:
Ooops. Wrong button.

mgrusin, 2018-08-13:
Thanks for the feedback! Any design is a series of sometimes difficult tradeoffs, and what works for one person may not work for another. Some of the reasons we chose the vertical connector are:

Price was one of the main drivers of this board. The vertical connector uses less real-estate and doesn't interfere with adjacent sewtabs, allowing a smaller and less-expensive board.

We've had considerable trouble in the past with "flat" USB connectors ripping off boards, and wanted to come up with a very strong solution for student use. The vertical connector is half surface-mount and half through-hole, and is extremely strong.

In testing we found that most users will temporarily attach a USB cable to program the board, then use the coin cell to power it. We've also found that the vertical connector is easier to attach a USB cable to in most situations (where the board is attached to the outside of a project). If a straight-out USB cable doesn't work well there are right-angle USB cables available that may solve these problems.

Sincere thanks for the feedback. We're always reevaluating our design choices and doing our best to incorporate what works best for our customers.

Closed 2018-08-15.

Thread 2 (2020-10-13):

LEDs interfering with SWD?

konistehrad, 2020-10-13:
I've been trying to program a new bootloader onto the LilyMini via `openocd`, and I haven't been able to successfully get any of either the Rpi bit bang interface or a CMSIS-DAP interface to talk to the board via the SWD pins on the back. Could the LEDs wired onto PA30 and PA31 be interfering with this? Any advice would be much appreciated.

Thanks!

konistehrad, 2020-10-14:
Bad cable, sorry!

Closed 2020-10-14.

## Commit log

2016-09-28 Added RGB "pin" designators to bplace
    [LilyMini_Protosnap.brd]
2016-09-28 Minor tweaks per board review checklist
    [LilyMini_Protosnap.brd, LilyMini_Protosnap.sch]
2016-09-28 Minor changes based on AC and Bob's advice
    Reduced paste on QFN and USB footprints by 25%
    [LilyMini_Protosnap.brd, LilyMini_Protosnap.sch]
2016-09-28 Found, fixed issue w QFN24 package :P
    Our libraries are the best.
    [LilyMini_Protosnap.brd, LilyMini_Protosnap.sch]
2016-09-29 Changed mouse bites from 0.02 to 0.015
    Per Advanced Circuits, annular around original 0.02 drill hits would
    reduce trace to hairline. Drills reduced to 0.015 to reduce this issue.
    Smaller drills may make snapping harder, evaluate on proto.
    [LilyMini_Protosnap.brd, LilyMini_Protosnap.sch]
2016-10-10 Minor changes pre review
    Enlarged copper on programming pins
    Added VBATT3 test point
    Added TDOCU text for test points
    [LilyMini_Protosnap.brd, LilyMini_Protosnap.sch]
2016-10-10 Minor updates
    Larger fiducials
    Sep version numbers on snap (1), LilyMini (1), light (2 - layout and
    part change from current)
    Added perforations
    [LilyMini_Protosnap.brd, LilyMini_Protosnap.sch]
2016-10-12 Changes per red review
    LED resistors to 150 ohm
    VBAT3V test point moved for selective solder
    USB P/N lines moved to rear of board for clearance and impedance control
    Perforations
    [LilyMini_Protosnap.brd, LilyMini_Protosnap.sch]
2016-10-13 Minor changes per checklist
    [LilyMini_Protosnap.brd]
2016-11-11 Fixed typo on schematic
    [LilyMini_Protosnap.sch]
2016-12-15 Copied schematic to hardware folder

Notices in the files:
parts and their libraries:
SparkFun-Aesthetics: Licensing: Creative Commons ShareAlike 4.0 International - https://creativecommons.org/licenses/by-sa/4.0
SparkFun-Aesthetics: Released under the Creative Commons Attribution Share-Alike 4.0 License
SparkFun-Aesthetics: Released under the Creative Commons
